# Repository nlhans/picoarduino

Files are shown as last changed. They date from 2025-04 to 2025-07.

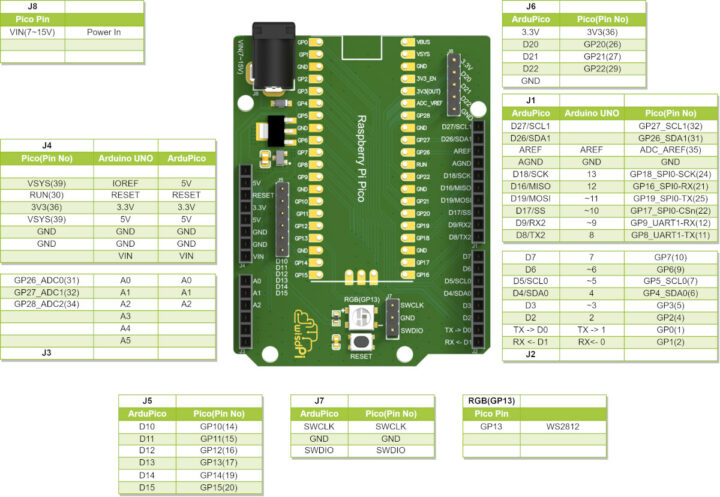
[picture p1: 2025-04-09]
resources/ArduPico-Pinout-diagram-720x497.jpg

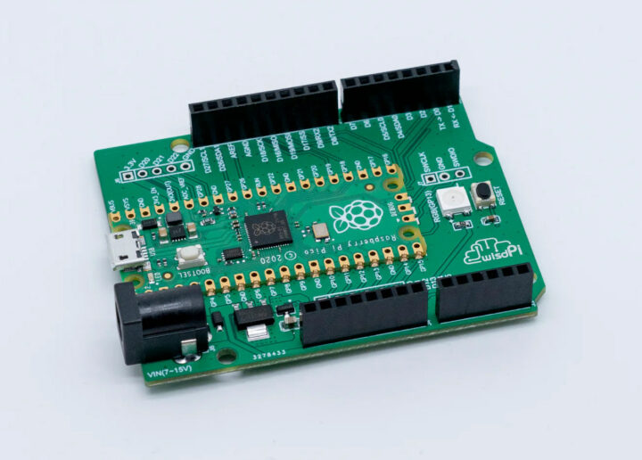
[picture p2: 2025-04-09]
resources/wisdPi-ArduPico-Raspberry-Pi-Pico-Arduino-baseboard-720x516.jpg

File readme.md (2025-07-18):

## (yet another) pico at arduino form factor board thingy

Wishlist: 
- power socket with 5V regulator (Vsys) also linked to Vin (shield compatibility)
- jumper switches (solder bridges on PCB bottom) for power selection: 5V or 3.3V
- multiplexer for 6 analog inputs (74HC4053?)

comments on first edition: 

Aangepaste schema/PCB layout voor een Raspberry Pico in Arduino jasje.

Uno compatible pinnen voor de Pico is niet gestandaardiseerd. Dus pinning overgenomen van FlexyPin versie: https://shop.pimoroni.com/products/raspberry-pi-pico-to-uno-flexypin-adapter?variant=40387747414099

A4-A6 zijn toegevoegd middels 74HC4053 mux en geschakeld met GPIO22. Hierdoor ontbreekt SCL/SDA helaas wel op A5/A6.

Verdere poorten:
SPI0 is op D10-D13 (losse 6-pin).
SPI1 zit op D16-D19.
I2C0 zit op D20/D21.
I2C1 zit o.a. op D2/D3.
UART0 zit op D0/D1.

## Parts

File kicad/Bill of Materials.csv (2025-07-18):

Reference | Qty | DNP | Exclude from BOM | Exclude from Board | Footprint | Manufacturer | POFarnell | POMouser | MPN
A1 | 1 |  | Excluded from BOM |  | Module:Arduino_UNO_R3
C1 | 1 |  |  |  | Capacitor_SMD:C_1206_3216Metric_Pad1.33x1.80mm_HandSolder | Samsung Electro-mechanics | 3013521 | 187-CL31B104KBCNNNC | CL31B104KBCNNNC
C2,C3 | 2 |  |  |  | Capacitor_SMD:C_1206_3216Metric_Pad1.33x1.80mm_HandSolder | KYOCERA AVX | 2852729 | 581-TAJB106M025RNJ | TAJB106M025RNJ
D1,D2 | 2 |  |  |  | Diode_SMD:D_SMB | STMicroelectronics | 1467550 | 511-STPS1L30U | STPS1L30U
H1,H2,H3,H4 | 4 |  | Excluded from BOM |  | MountingHole:MountingHole_3.2mm_M3_DIN965
J1 | 1 |  |  |  | Connector_PinHeader_2.54mm:PinHeader_2x03_P2.54mm_Vertical
J2 | 1 |  |  |  | Connector_PinHeader_2.54mm:PinHeader_1x03_P2.54mm_Horizontal
J3 | 1 |  |  |  | Connector_BarrelJack:BarrelJack_Horizontal | GCT | 3873896 | 640-DCJ235-05-A-K1-K | DCJ235-05-A-K1-K
M1 | 1 |  |  |  | Library:RaspberryPi_Pico
SW1 | 1 |  |  |  | Library:Button_Omron_B3SN_6.0x6.0mm | C&K | 3941499 | 611-PTS526SM20S21LFS | PTS526SM20SMTR21
U1 | 1 |  |  |  | Package_SO:SOIC-16_3.9x9.9mm_P1.27mm | Nexperia | 3441376 | 771-LV4053D118 | 74LV4053D,118
U2 | 1 |  |  |  | Package_TO_SOT_SMD:SOT-223-3_TabPin2 | Texas Instruments | 3122345 | 595-TLV1117-50IDCYR | TLV1117-50IDCYR

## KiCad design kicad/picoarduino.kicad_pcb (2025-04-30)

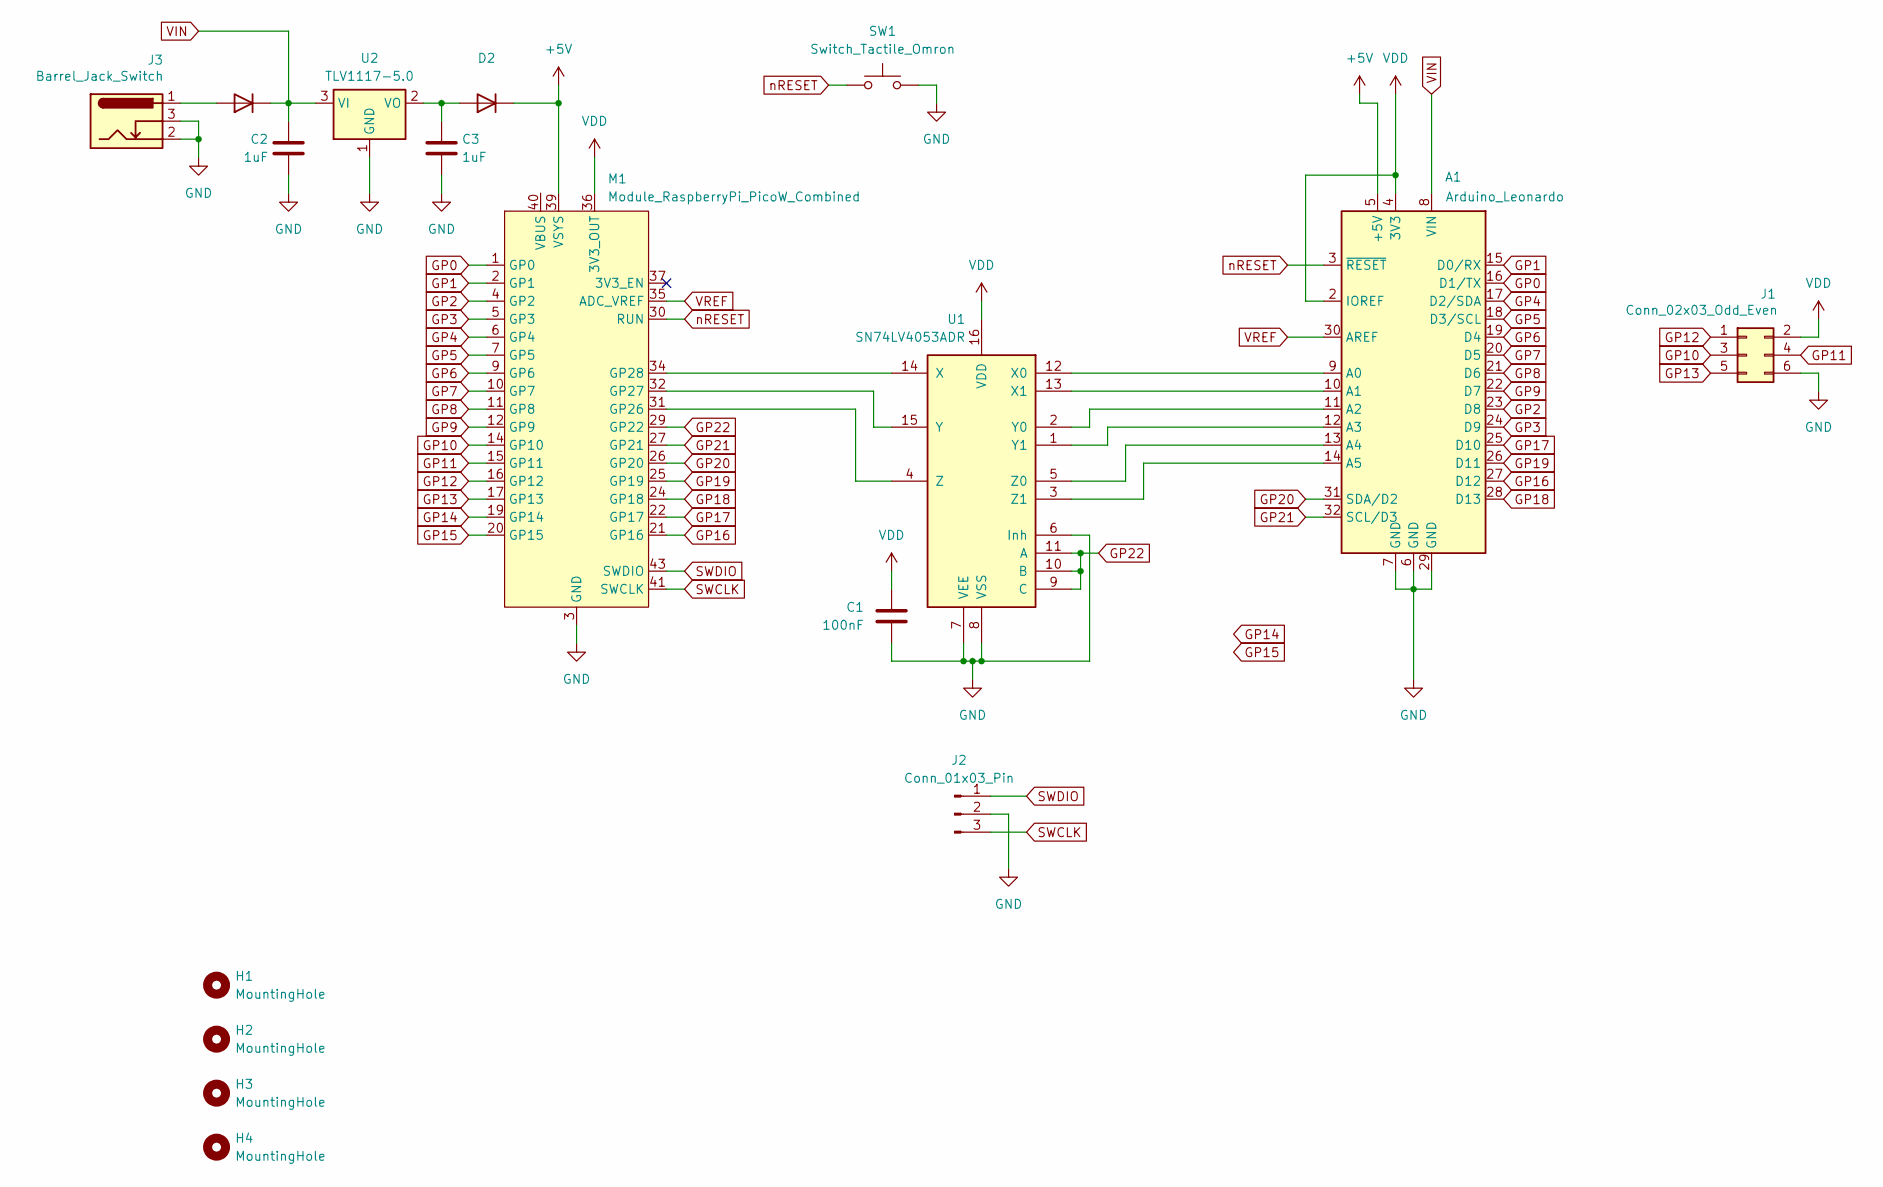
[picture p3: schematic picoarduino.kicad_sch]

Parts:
A1: Arduino_Leonardo; Arduino_UNO_R3
C1: 100nF; C_1206_3216Metric_Pad1.33x1.80mm_HandSolder
C2, C3: 1uF; C_1206_3216Metric_Pad1.33x1.80mm_HandSolder
D1, D2: D_SMB
H1, H2, H3, H4: MountingHole; MountingHole_3.2mm_M3_DIN965
J1: Conn_02x03_Odd_Even; PinHeader_2x03_P2.54mm_Vertical
J2: Conn_01x03_Pin; PinHeader_1x03_P2.54mm_Horizontal
J3: Barrel_Jack_Switch; BarrelJack_Horizontal
M1: Module_RaspberryPi_PicoW_Combined; RaspberryPi_Pico
SW1: Switch_Tactile_Omron; Button_Omron_B3SN_6.0x6.0mm
U1: SN74LV4053ADR; SOIC-16_3.9x9.9mm_P1.27mm; MPN SN74LV4053ADR
U2: TLV1117-5.0; SOT-223-3_TabPin2

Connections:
+5V: A1.5 (+5V), D2.1 (K), M1.39 (VSYS)
GND: A1.6 (GND), A1.7 (GND), A1.29 (GND), C1.2, C2.2, C3.2, J1.6, J2.2, J3.2, J3.3, M1.3 (GND), M1.8 (GND), M1.13 (GND), M1.18 (GND), M1.23 (GND), M1.28 (GND), M1.33 (GND), M1.38 (GND), M1.42 (GND), SW1.2, U1.6 (Inh), U1.7 (VEE), U1.8 (VSS), U2.1 (GND)
GP0: A1.16 (D1/TX), M1.1 (GP0)
GP1: A1.15 (D0/RX), M1.2 (GP1)
GP2: A1.23 (D8), M1.4 (GP2)
GP3: A1.24 (D9), M1.5 (GP3)
GP4: A1.17 (D2/SDA), M1.6 (GP4)
GP5: A1.18 (D3/SCL), M1.7 (GP5)
GP6: A1.19 (D4), M1.9 (GP6)
GP7: A1.20 (D5), M1.10 (GP7)
GP8: A1.21 (D6), M1.11 (GP8)
GP9: A1.22 (D7), M1.12 (GP9)
GP10: J1.3, M1.14 (GP10)
GP11: J1.4, M1.15 (GP11)
GP12: J1.1, M1.16 (GP12)
GP13: J1.5, M1.17 (GP13)
GP14: M1.19 (GP14)
GP15: M1.20 (GP15)
GP16: A1.27 (D12), M1.21 (GP16)
GP17: A1.25 (D10), M1.22 (GP17)
GP18: A1.28 (D13), M1.24 (GP18)
GP19: A1.26 (D11), M1.25 (GP19)
GP20: A1.31 (SDA/D2), M1.26 (GP20)
GP21: A1.32 (SCL/D3), M1.27 (GP21)
GP22: M1.29 (GP22), U1.9 (C), U1.10 (B), U1.11 (A)
unnamed: A1.9 (A0), U1.12 (X0)
unnamed: A1.10 (A1), U1.13 (X1)
unnamed: A1.11 (A2), U1.2 (Y0)
unnamed: A1.12 (A3), U1.1 (Y1)
unnamed: A1.13 (A4), U1.5 (Z0)
unnamed: A1.14 (A5), U1.3 (Z1)
unnamed: D1.2 (A), J3.1
unnamed: C3.1, D2.2 (A), U2.2 (VO)
unnamed: M1.31 (GP26), U1.4 (Z)
unnamed: M1.32 (GP27), U1.15 (Y)
unnamed: M1.34 (GP28), U1.14 (X)
SWCLK: J2.3, M1.41 (SWCLK)
SWDIO: J2.1, M1.43 (SWDIO)
VDD: A1.2 (IOREF), A1.4 (3V3), C1.1, J1.2, M1.36 (3V3_OUT), U1.16 (VDD)
VIN: A1.8 (VIN), C2.1, D1.1 (K), U2.3 (VI)
VREF: A1.30 (AREF), M1.35 (ADC_VREF)
nRESET: A1.3 (~RESET), M1.30 (RUN), SW1.1

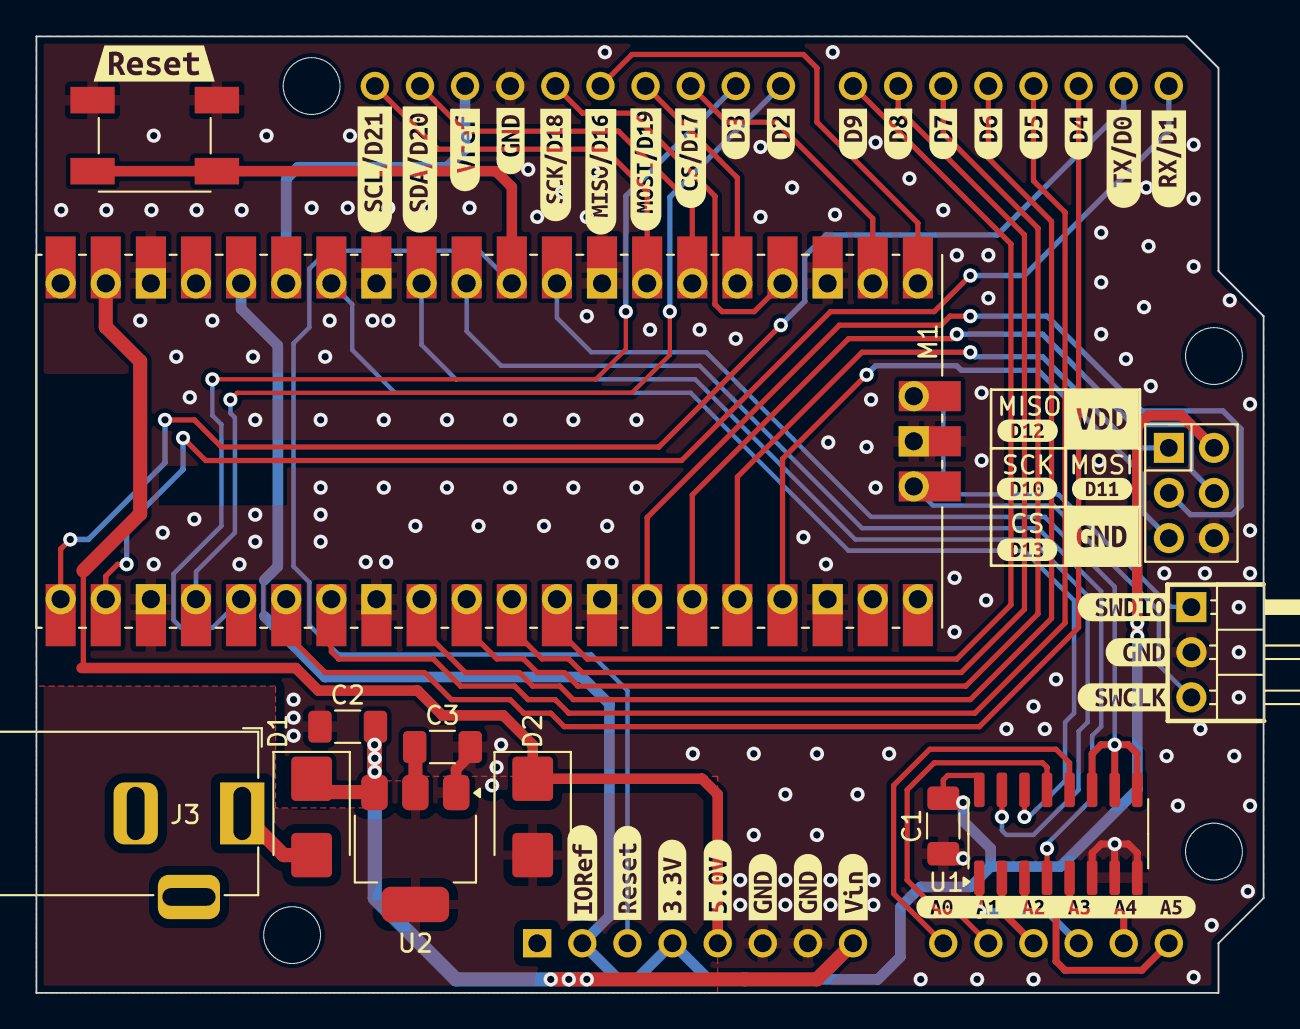
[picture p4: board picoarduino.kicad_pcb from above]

Board: 2 copper layers, 69.1 x 53.8 mm, 53 parts (1 on the bottom side), 40 nets.

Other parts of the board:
kibuzzard-6811E7BB: G***; kibuzzard-6811E7BB
kibuzzard-6811E7CA: G***; kibuzzard-6811E7CA
kibuzzard-6811E7F6: G***; kibuzzard-6811E7F6
kibuzzard-6811E7FD: G***; kibuzzard-6811E7FD
kibuzzard-6811E8A2: G***; kibuzzard-6811E8A2
kibuzzard-6811E8AA: G***; kibuzzard-6811E8AA
kibuzzard-6811E8B1: G***; kibuzzard-6811E8B1
kibuzzard-6811E8BA: G***; kibuzzard-6811E8BA
kibuzzard-6811E8E7: G***; kibuzzard-6811E8E7
kibuzzard-6811E8EF: G***; kibuzzard-6811E8EF
kibuzzard-6811E80A: G***; kibuzzard-6811E80A
kibuzzard-6811E81B: G***; kibuzzard-6811E81B
kibuzzard-6811E84F: G***; kibuzzard-6811E84F
kibuzzard-6811E88B: G***; kibuzzard-6811E88B
kibuzzard-6811E89B: G***; kibuzzard-6811E89B
kibuzzard-6811E805: G***; kibuzzard-6811E805
kibuzzard-6811E813: G***; kibuzzard-6811E813
kibuzzard-6811E822: G***; kibuzzard-6811E822
kibuzzard-6811E893: G***; kibuzzard-6811E893
kibuzzard-6811E907: G***; kibuzzard-6811E907
kibuzzard-6811ECD5: G***; kibuzzard-6811ECD5
kibuzzard-6811ECDC: G***; kibuzzard-6811ECDC
kibuzzard-6811ED2E: G***; kibuzzard-6811ED2E
kibuzzard-6811ED4D: G***; kibuzzard-6811ED4D
kibuzzard-6811ED38: G***; kibuzzard-6811ED38
kibuzzard-6811ED44: G***; kibuzzard-6811ED44
kibuzzard-6811ED69: G***; kibuzzard-6811ED69
kibuzzard-6811ED70: G***; kibuzzard-6811ED70
kibuzzard-6811EEF0: G***; kibuzzard-6811EEF0
kibuzzard-681112EB: G***; kibuzzard-681112EB
kibuzzard-681112F5: G***; kibuzzard-681112F5
kibuzzard-681112FC: G***; kibuzzard-681112FC
kibuzzard-681135A2: G***; kibuzzard-681135A2
kibuzzard-68111259: G***; kibuzzard-68111259
kibuzzard-68111301: G***; kibuzzard-68111301
kibuzzard-68113590: G***; kibuzzard-68113590

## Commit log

2025-04-09 added kicad files and datasheets
    [picoarduino.kicad_pcb, picoarduino.kicad_sch]
2025-04-30 Schematic and PCB
    [picoarduino.kicad_pcb, picoarduino.kicad_sch]
2025-07-18 Bill of materials
    [Bill of Materials.csv, picoarduino.kicad_sch]
